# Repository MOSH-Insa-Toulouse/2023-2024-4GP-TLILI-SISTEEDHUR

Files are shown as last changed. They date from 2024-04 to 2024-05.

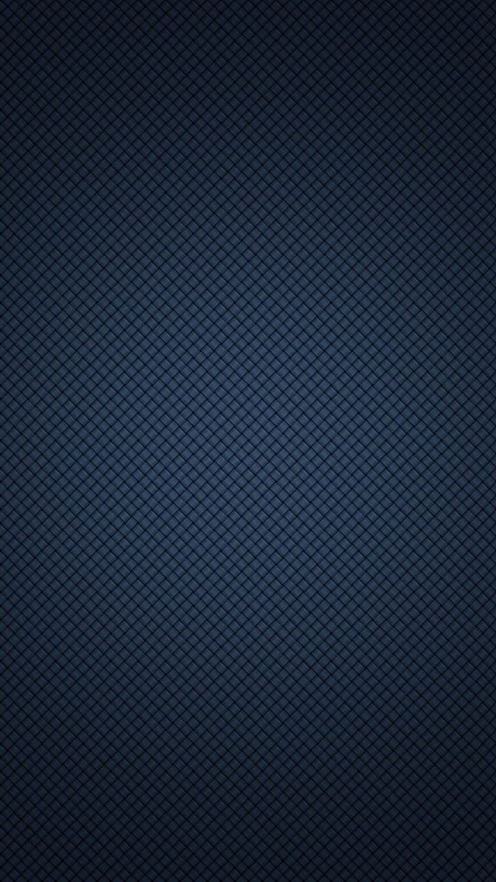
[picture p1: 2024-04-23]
Images/APKlike/Carbon Fiber.jpg

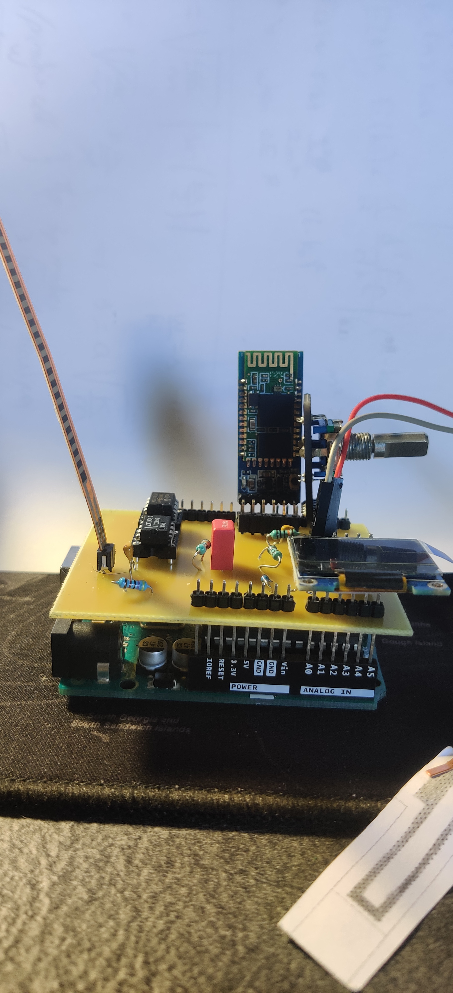
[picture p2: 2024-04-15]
Images/PCB/Shield3.jpg

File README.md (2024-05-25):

<h1 align="center"> Projet Capteur graphite </h1>
<h2 align="center"> TLILI Maxime - SISTEEDHUR Lakshitaa </h2>
<h3 align="center"> INSA Toulouse - département Génie Physique - 2024 </h3>

Shield2

## Introduction au projet

&nbsp;&nbsp;&nbsp;&nbsp;Ce projet se construit dans le cadre de l'UF "Du capteur au banc de test" de la 4ème année du parcours Génie Physique à l'Institut National des Sciences Appliquées (INSA) de Toulouse. Il permet une approche novatrice et lowtech dans la mesure de contrainte en se basant sur les propriétés du graphite. Il s’appuie sur l’étude de capteurs de contrainte en graphite (système granulaire) dont la résistance varie suivant la déformation du capteur (Pencil Drawn Strain Gauges and Chemiresistors on Paper Cheng-Wei Lin*, Zhibo Zhao*, Jaemyung Kim & Jiaxing Huang Department of Materials Science and Engineering, Northwestern University 2220 Campus Drive, Evanston, IL, 60208, USA).

&nbsp;&nbsp;&nbsp;&nbsp;Au cours de ce projet, nous avons réalisé un dispositif permettant de relever des mesures de contrainte à partir d'une feuille en papier sur laquelle était déposée du graphène. En déformant le capteur, sa résistance est modifiée.. Il est donc possible de réaliser un capteur de déformation low-tech, que nous appellerons par la suite "capteur graphite". Dans un premier temps, nous avons simulé le comportement du circuit analogique sur le logiciel LTSpice. Ce circuit a le double rôle d’amplifier (via un amplificateur transimpédance) et de filtrer le signal délivré par le capteur. Ensuite, un code Arduino permettant la mesure de résistance et le contrôle des différents éléments du circuit (écran OLED, module Bluetooth et potentiomètre digital) a été réalisé. Nous avons préalablement testé notre circuit et le code en montant les différents éléments sur une breadboard. Ensuite, nous avons designé un PCB grâce au logiciel KiCad constituant le shield qui se fixe sur une carte Arduino UNO.

## Livrables

Les livrables du projet sont :
    - [] Le PCB du Shield Arduino
    - [] Le code Arduino permettant de faire la mesure de la résistance du capteur graphite
    - [] L'application Android pour un pilotage bluetooth du système
    - [] le banc de test du capteur
    - [] Le datasheet du capteur
    
Pour notre projet, nous avons opté pour ajouter un écran OLED servant de menu, du flex sensor commercial pour avoir un comparatif avec notre capteur, ainsi que d'un encodeur rotatoire pour différentes fonctionnalités.

## Sommaire
***
- [Matériel nécéssaire](#matériel-nécéssaire)
- [1. Simulation électronique du capteur graphite sous LTSpice](#1-simulation-électronique-du-capteur-graphite-sous-ltspice)
- [2. PCB via KiCad](#2-pcb-via-kicad)
- [3. Réalisation du Shield](#3-réalisation-du-shield)
- [4. Code Arduino](#4-code-arduino)
- [5. Application Android](#5-application-android)
- [6. Banc de test](#6-banc-de-test)
- [Datasheet](#datasheet)
- [Contact](#contact)

## Matériel nécéssaire

 - 1 Carte [Arduino UNO](https://store.arduino.cc/products/arduino-uno-rev3)
 - 1 Ecran [OLED-01](https://www.gotronic.fr/art-afficheur-oled-0-96-i2c-oled01-31506.htm)  128x64
 - 1 Amplificateur Opérationnel [LTC1050](https://www.analog.com/en/products/ltc1050.html)
 - 1 Potentiomètre Digital [MCP-41050](https://www.microchip.com/en-us/product/mcp41050)
 - 1 Module Bluetooth [HC-05](https://www.gotronic.fr/art-module-bluetooth-hc05-26097.htm)
 - 1 Encodeur Rotatoire [KY-040](https://www.az-delivery.de/fr/products/drehimpulsgeber-modul)
 - 1 Capteur [FLEXSENSOR](https://store.spectrasymbol.com/products/flex-sensor)
 - 5 Résistances (X2 100kOhm, X1 47kOhm, X1 10kOhm, X1 1kOhm)
 - 4 Condensateurs (X3 100nF, X1 1uF)
 - Crayons (HB, 2B,...)
 - Modèle papier du capteur graphite

## 1. Simulation électronique du capteur graphite sous LTSpice

&nbsp;&nbsp;&nbsp;&nbsp;Sur le logiciel LTSpice, nous avons réalisé une simulation électrique du circuit par application du schéma suivant :

Circuit LTSpice

La résistance variable de notre capteur étant de l'ordre du GigaOhm, le courant généré est très faible (de l'ordre de quelques nA). Afin de délivrer une tension suffisante au niveau du convertisseur analogique-numérique d'une carte Arduino UNO, il est nécessaire d'amplifier le signal en amont de la mesure. On réalise donc un amplificateur opérationnel transimpédance. Nous avons choisi le circuit amplificateur LTC 1050 au vu de ses paramètres de tension d'offset faible. Celle-ci ne doit pas fausser les valeurs de tensions que reçoit l'Arduino. Il est aussi nécessaire de réaliser un traitement du bruit lié à l'environnement de la mesure. C'est le rôle des différents filtres qui atténuent les bruits du réseau électrique et des horloges des composants.

Cette simulation nous permet de savoir que l'Arduino UNO est capable de mesurer le signal du capteur.

## 2. PCB via KiCad

### a. Création du PCB
&nbsp;&nbsp;&nbsp;&nbsp;Cette partie concerne la conception du circuit transimpédance sur Kicad 8.0 avec l'ajout de divers composants : 
- La résistance R2 a été remplacé par le potentiomètre digital MPC-41050. Il permet d'ajuster le gain du montage en simulant une résistance variable entre 0 et 50kOhms 
- Un module bluetooth HC-05 a été ajouté pour rendre possible une communication avec une application mobile
- Un écran OLED permet de faire l'interface homme-machine en affichant les informations
- Un flexsensor a été ajouté en tant que capteur témoin
- Un encodeur rotatoire ajoute des fonctionalités pour interagir avec les autres composants. ça permet de naviguer dans les menus de l'écran OLED et de lancer la mesure

A partir d'un template d'une carte Arduino UNO, il a fallu :
- Concevoir le schématique du circuit en important et en créant les symbôles pour chaque composant
- Corréler chaque composant à une empreinte réelle en fonction de ses caractéristiques physiques (nombre de pins, distance entre deux pins,...)
- Placer les composants sur la partie schématique et réaliser le routage du circuit
- Poser un plan de masse pour faire le référencement au GND
Afin de s'assurer de la validité du PCB, nous avons été contraint à l'utilisation de deux vias.

Nous avons listé ci-dessous les symbôles et empreintes des composants, ainsi que le schématique et son PCB final

### b. Symbôles et empreintes

- amplificateur transimpédance

Amplificateur transimpédance Symbol

- Capteur graphite

Capteur Graphite Symbol
Capteur Graphite footprint

- Amplificateur LTC1050

LTC 1050 Symbol
LTC 1050 footprint

- Flexsensor

Flexsensor Symbol
Flexsensor footprint

- Module bluetooth HC-05

Bluetooth HC-05 Symbol
Bluetooth HC-05 footprint

- Potentiomètre digital MPC41050

MPC41050 Symbol
MCP41050 footprint

- Encodeur rotatoire KY-040
KY-040 Symbol
KY-040 footprint

- Ecran OLED
OLED Screen Symbol
OLED Screen footprint

### c. Schématique et PCB final
- Schéma complet

    Schematics

- PCB

    PCB2
    PCB1

- Modèle 3D

Top view
Angle view

## 3. Réalisation du Shield

&nbsp;&nbsp;&nbsp;&nbsp;Une fois le schéma PCB réalisé, nous avons sorti le circuit sur un calque à l'échelle 1:1. Il a joué le rôle de masque dans la gravure chimique sur une plaquette d'époxy recouverte d'une couche de cuivre d'une épaisseur d'environ 60um. La plaquette a été couverte d'une résine positive, puis elle a été insolé aux UVs. Nous avons plongé la plaquette dans un révélateur et dans du perchlorure de fer pour s'affranchir de la partie de la résine non isolée et du cuivre non protégé. Cette opération s'est déroulée au sein du bâtiment du département du Génie Electrique et Informatique de l'INSA Toulouse.

&nbsp;&nbsp;&nbsp;&nbsp;L'étape suivante a été le perçage mécanique des trous sur la plaquette, et la soudure des différents composants. Nous avons utilisés deux forets mécaniques : un de diamètre 1mm pour les broches de connexion avec la carte Arduino, et un de diamètre 0.8mm pour tout autre trou. Pour ce qui est de nos deux vias, nous avons soudé des fils sur la partie non visible du PCB.

Shield1

## 4. Code Arduino

&nbsp;&nbsp;&nbsp;&nbsp;Pour faire la mesure de la résistance, nous avons créé un programme Arduino. Lorsqu'on maintient appuyé le bouton de l'encodeur rotatoire, la mesure de résistance se fait à un intervalle d'environ une seconde. La valeur nous est transmise par le biais de l'écran OLED.

&nbsp;&nbsp;&nbsp;&nbsp;Nous avons fournis trois fichiers de code :

- [Capteur2024V1.0.1](https://github.com/MOSH-Insa-Toulouse/2023-2024-4GP-TLILI-SISTEEDHUR/tree/main/Arduino/Capteur2024V1.0.1) : c'est la version qui fournit trois menus sur l'écran OLED permettant de choisir entre le mode Mesureflex, le mode MesureCG, et le mode calibration. Ce programme ne permet pas de faire de mesures. Dès lors que nous demandons de lire une mesure, l'écran OLED ne s'initialise plus et le programme plante
- [Capteur2024V2](https://github.com/MOSH-Insa-Toulouse/2023-2024-4GP-TLILI-SISTEEDHUR/tree/main/Arduino/Capteur2024V2.0/Capteur2024_V2.0) : C'est la version qui marche. Elle décrit le protocole présenté au dessus.
- [Test Components](https://github.com/MOSH-Insa-Toulouse/2023-2024-4GP-TLILI-SISTEEDHUR/tree/main/Arduino/Test%20Components/Test_OLED) : c'est un programme permettant de tester l'écran OLED.

Affichage_ecran_OLED

## 5. Application Android

&nbsp;&nbsp;&nbsp;&nbsp;Nous avons réalisé une application android nommée FlexiGraphite.apk. Elle permet d'interagir par bluetooth avec le capteur graphite et de relever notamment la valeur de la résistance du capteur graphite.

Logo :
FlexiGraphite

Menu de l'application :
Menu FlexiGraphite

On retrouve 3 parties sur le menu : 
- La connexion bluetooth au dessus, avec la possibilité de voir l'état de la connexion et de se déconnecter de tout appareil.
- L'onglet "Mesure" servant à y afficher les mesures de la résistance graphite.
- L'onglet "Calibration" qui permet de piloter le lancement de la calibration du gain transimpédance.

## 6. Banc de test

&nbsp;&nbsp;&nbsp;&nbsp;Afin de tester notre capteur, nous avons réalisé un banc de test. Le support est un ensemble de demi-cercles dont le rayon varie. 

BancDeTest
Formule

Pour les crayons B et HB, on calcule la déformation en fonction du rayon du banc de test et on fait la mesure de résistance. On reporte les valeurs dans un graphe pour tracer l'évolution de la variation de résistance en fonction de la déformation.

deformation en compression

Déformation en tension

Deformation flexsensor

## Datasheet
Le datasheet de notre capteur se trouve [ici](https://github.com/MOSH-Insa-Toulouse/2023-2024-4GP-TLILI-SISTEEDHUR/blob/main/Datasheet/Datasheet%20Graphite%20Flex%20Sensor.pdf). 

## **Contact:**
- Maxime Tlili : tlili@insa-toulouse.fr
- Lakshitaa Devi Sisteedhur : sisteedh@insa-toulouse.fr

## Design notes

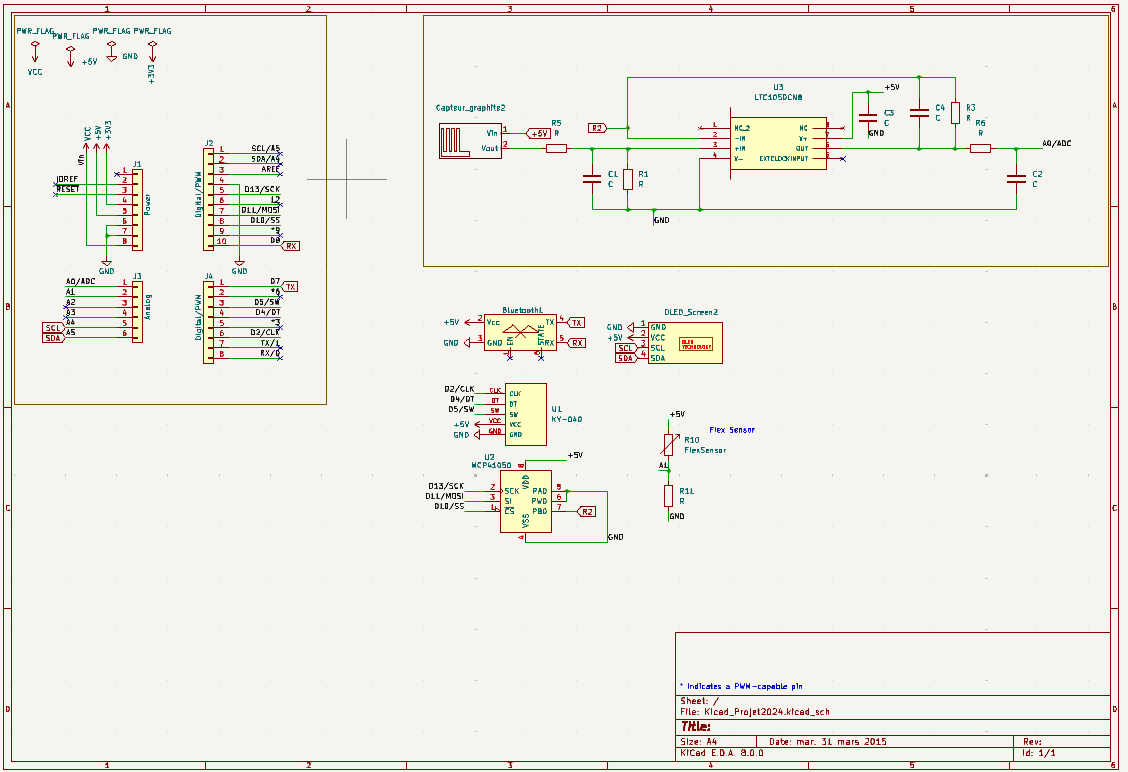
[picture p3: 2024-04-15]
Images/Kicad/Schematics.png

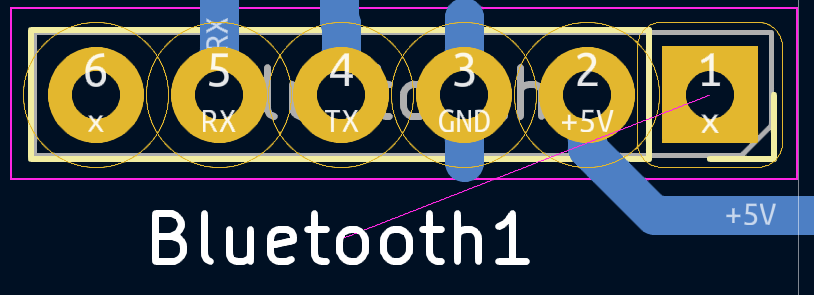
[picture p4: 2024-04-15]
Images/Kicad/Bluetooth HC-05 footprint.png

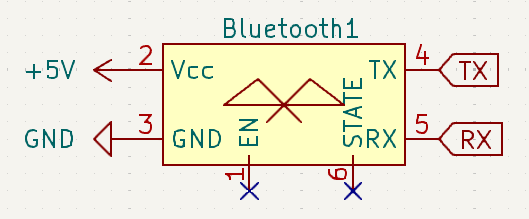
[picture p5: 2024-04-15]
Images/Kicad/Bluetooth HC-05 Symbol.png

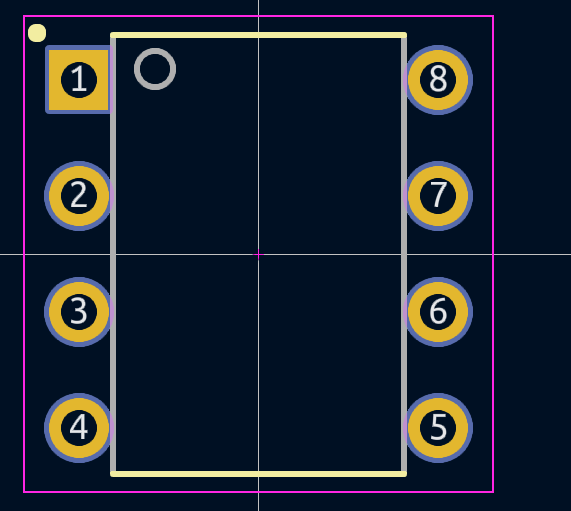
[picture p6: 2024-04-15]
Images/Kicad/MCP41050 footprint.png

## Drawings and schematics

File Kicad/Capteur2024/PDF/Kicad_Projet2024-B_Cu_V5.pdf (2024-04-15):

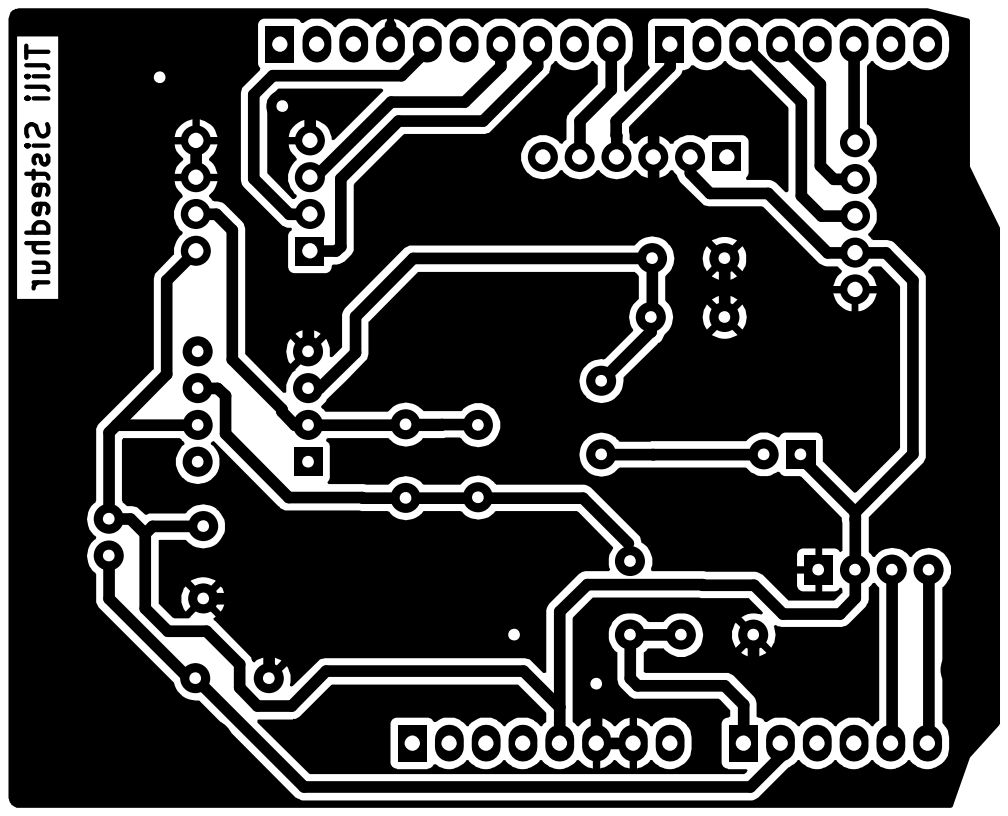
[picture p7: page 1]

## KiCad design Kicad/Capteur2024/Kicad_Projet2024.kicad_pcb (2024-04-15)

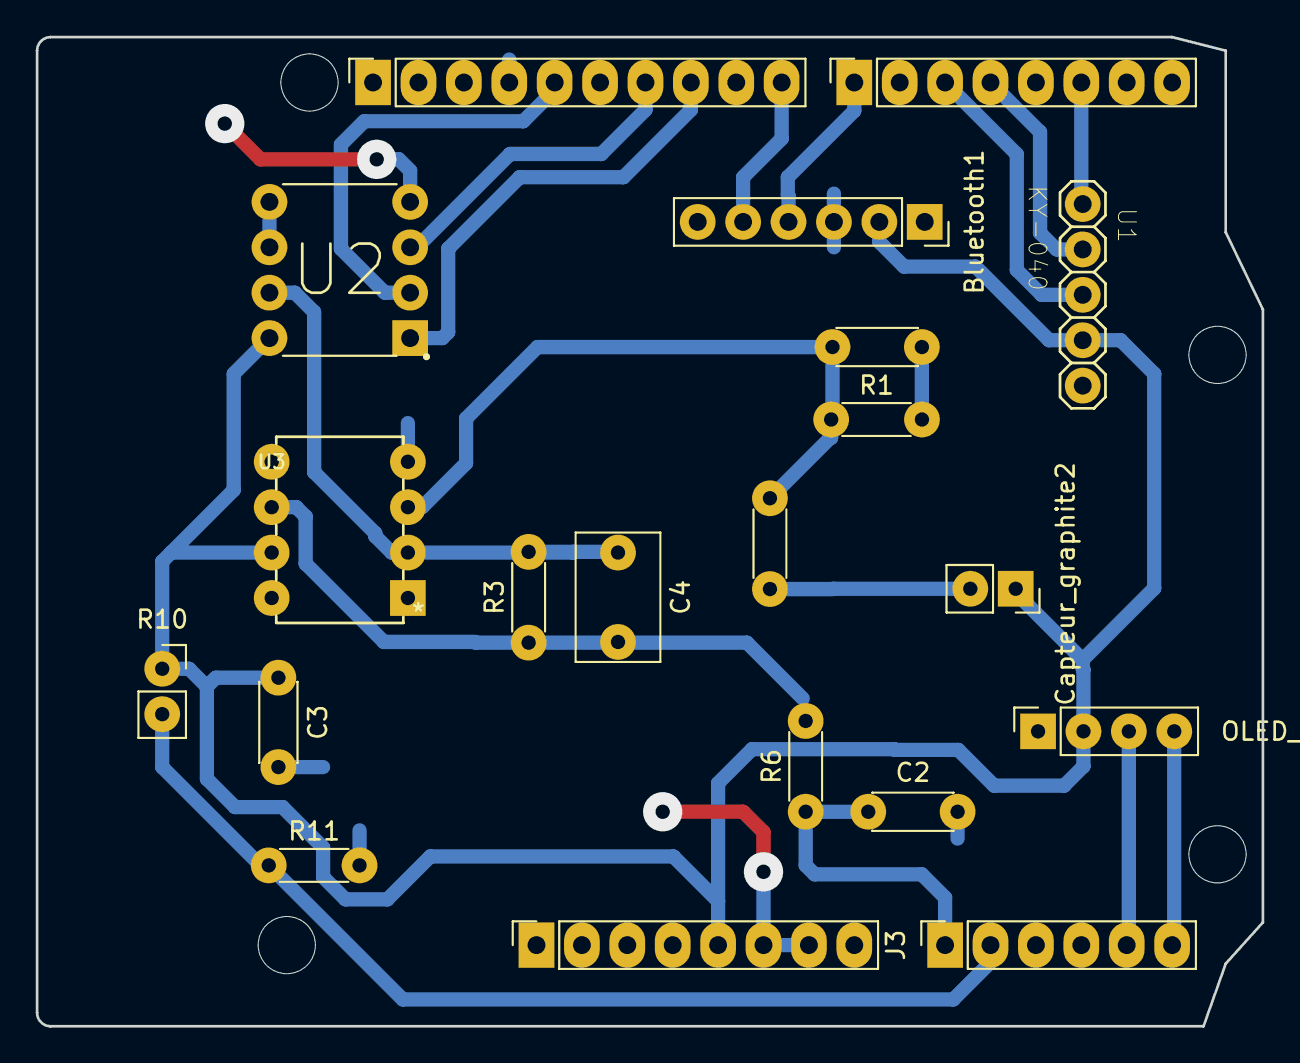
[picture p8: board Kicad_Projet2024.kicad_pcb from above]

Board: 2 copper layers, 68.6 x 55.3 mm, 24 parts (0 on the bottom side), 18 nets.

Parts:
Bluetooth1: PinSocket_1x06_P2.54mm_Vertical
C1, C2, C3: C; C_Disc_D4.3mm_W1.9mm_P5.00mm
C4: C; C_Rect_L7.0mm_W4.5mm_P5.00mm
Capteur_graphite2: PinSocket_1x02_P2.54mm_Vertical
J1: Power; PinSocket_1x08_P2.54mm_Vertical
J2: Digital/PWM; PinSocket_1x10_P2.54mm_Vertical
J3: Analog; PinSocket_1x06_P2.54mm_Vertical
J4: Digital/PWM; PinSocket_1x08_P2.54mm_Vertical
MH1, MH2, MH3, MH4: MountingHole_3.2mm
OLED_Screen2: PinSocket_1x04_P2.54mm_Vertical
R1, R3, R5, R6, R11: R; R_Axial_DIN0204_L3.6mm_D1.6mm_P5.08mm_Horizontal
R10: FlexSensor; PinSocket_1x02_P2.54mm_Vertical
U1: KY-040; KY-040-PORT
U2: MCP41050; MPC41050_IP
U3: LTC1050CN8

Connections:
+5V: Bluetooth1.2 (Vcc), C3.1, Capteur_graphite2.1 (Vin), J1.5, OLED_Screen2.2 (VCC), R10.1, U1.VCC, U2.8 (VDD), U3.7 (V+)
/A0/ADC: C2.1, J3.1, R6.1
/A1: J3.2, R10.2, R11.1
/D2/CLK: J4.6, U1.CLK
/D4/DT: J4.4, U1.DT
/D5/SW: J4.3, U1.SW
/D10/SS: J2.8, U2.1 (~CS)
/D11/MOSI: J2.7, U2.3 (SI)
/D13/SCK: J2.5, U2.2 (SCK)
GND: Bluetooth1.3 (GND), C1.2, C2.2, C3.2, J1.6, J1.7, J2.4, OLED_Screen2.1 (GND), R1.2, R11.2, U1.GND, U2.4 (VSS), U2.5 (PA0), U2.6 (PW0), U3.4 (V-)
unnamed: Capteur_graphite2.2 (Vout), R5.1
unnamed: C1.1, R1.1, R5.2, U3.3 (+IN)
unnamed: C4.2, R3.1, R6.2, U3.6 (OUT)
R2: C4.1, R3.2, U2.7 (PB0), U3.2 (-IN)
RX: Bluetooth1.5 (RX), J2.10
SCL: J3.5, OLED_Screen2.3 (SCL)
SDA: J3.6, OLED_Screen2.4 (SDA)
TX: Bluetooth1.4 (TX), J4.1

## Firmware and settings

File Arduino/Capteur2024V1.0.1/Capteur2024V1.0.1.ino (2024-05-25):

#include <SoftwareSerial.h>                 //Module Bluetooth
#include <Adafruit_SSD1306.h>               //Ecran OLED
#include <Adafruit_GFX.h>
#include <SPI.h>                            //Potentiometre MCP41xxx


    // ~~~~~~~~~~~~ Définition des pins ~~~~~~~~~~~~ //

#define ADCPin A0                           // Ampli CG
#define flexPin A1                          // FlexSensor
#define encoder0PinA  2                     // CLK Encodeur KY-040
#define encoder0PinB  4                     // DT Encodeur KY-040
#define Switch 5                            // Switch Encodeur KY-040
#define txPin 7                             // A raccorder au TX du HC-05
#define rxPin 8                             // A raccorder au RX du HC-05
#define csMCpin 10                          // Slave Select du potentiometre

/*
SRD OLED- to analog pin A4
CLK OLED- to analog pin A5
SDI MCP41- to digital pin 11 (MOSI pin)
CLK MCP41- to digital pin 13 (SCK pin)
*/

#define baudrate 9600

    // ~~~~~~~~~~~~ Paramètres de l'écran OLED ~~~~~~~~~~~~ //

#define nombreDePixelsEnLargeur 128         // Largeur de l'écran OLED en pixel
#define nombreDePixelsEnHauteur 64          // Hauteur de l'écran OLED en pixel
#define brocheResetOLED         -1          // Reset de l'OLED partagé avec l'Arduino
#define adresseI2CecranOLED     0x3C        // Adresse I2C de l'écran OLED 

int currentMode = 0;                        // Mode actuel du menu
#define NUM_MODES 3                         // Nombre total de modes disponibles
String modeNames[NUM_MODES] = {"Mesure CG", "Mesure Flex", "Calibration"};  // Noms des modes

    // ~~~~~~~~~~~~ Paramètres du potentiomètre digital ~~~~~~~~~~~~ //

const int  maxPositions    = 256;           // wiper can move from 0 to 255 = 256 positions
const long rAB             = 46250;         // 50k pot resistance between terminals A and B, 
                                            // mais pour ajuster au multimètre, je mets 46250 : à vérifier
const byte rWiper          = 125;           // 125 ohms pot wiper resistance
const byte pot0            = 0x11;          // pot0 addr // B 0001 0001
const byte pot0Shutdown    = 0x21;          // pot0 shutdown // B 0010 0001

    // ~~~~~~~~~~~~ Paramètres du flexsensor ~~~~~~~~~~~~ //

const float VCC = 5;
const float flexR_DIV = 47000.0;
const float flexflatResistance = 30000.0;
const float flexbendResistance = 1000.0;


volatile unsigned int encoder0Pos = 0; //Initialisation de la position de l'encodeur

SoftwareSerial Bluetooth_Serial(rxPin ,txPin);
Adafruit_SSD1306 ecranOLED(nombreDePixelsEnLargeur, nombreDePixelsEnHauteur, &Wire, brocheResetOLED);


    // ~~~~~~~~~~~~ Paramètres de mesure ~~~~~~~~~~~~//

float Calibre = pow(10,-6);               // Afin d'avoir des Mohms
unsigned long antidelay = 0;              // Eviter le delay 
const long interval = 500;                // Cadencement de l'acquisition


    // ~~~~~~~~~~~~ Fonctions ~~~~~~~~~~~~ //

long setPotWiper(int addr, int pos) {   // Fonction permettant de fixer la position du potentiomètre 
                                        // Et donc de fixer la valeur de R2. Affiche la postion et la valeur de R2
  pos = constrain(pos, 0, 255);         // On limite les pads de 0 à 255
  digitalWrite(csMCpin, LOW);             // En position LOW, on active le chip select qui nous permet d'écrire    
  SPI.transfer(addr);                   // Configurer la position du potentiomètre "addr" sur "pos"
  SPI.transfer(pos);
  digitalWrite(csMCpin, HIGH);            // En position HIGH, on se déconnecte du CS

  long resistanceWB = ((rAB * pos) / maxPositions ) + rWiper; //Formule donnée dans la datasheet liant R2 et les paramètres
  
  return resistanceWB;
}

void calibration(){             //Fonction permettant de réaliser une calibration de la résistance R2 de l'ampli
  
  float R2_value;
  float Tension_sortie;         // variable qui stocke la tension en sortie de l'ampli
  int i = 0;
  do
  {
      R2_value = setPotWiper(pot0, i);
      Tension_sortie = ADCPin;
      delay(200); // A vérifier si le delai n'est pas trop court
      i++;
  } while ((/*Ampli A0 */ Tension_sortie <2.5 ) || (i<256)); //On set le potentio à sa valeur min et on récupère la valeur en sortie
                                              //de l'ampli. On répète l'opération pour se rapprocher des 2.5V (au milieu de la gamme de l'arduino) 

}

void bluetooth(){                 // A vérifier si important et à mettre dans le loop//
    int i = 0; 
	char someChar[32] ={0};
	//when characters arrive over the serial port...

	while (Serial.available()) {
	   do{
		someChar[i++] = Serial.read();
		delay(3);		
	   }while (Serial.available() > 0);
	   
	   Bluetooth_Serial.println(someChar); 
	   Serial.println(someChar); 
	}
	while (Bluetooth_Serial.available()) {
		Serial.print((char)Bluetooth_Serial.read());
	}
}

void doEncoder() {              //Paramètrage de l'encodeur rotatoire
  if (digitalRead(encoder0PinB)==HIGH) {  //On tourne l'encodeur dans le sens anti-trigonométrique. Incrémentation de la position//
    encoder0Pos++;
  } else {                                //On tourne l'encodeur dans le sens trigonométrique. Décrémentation de la position//
    encoder0Pos--;
  }
}

void mesureFlex() {             //Fait la mesure de la résistance et de l'angle du capteur
  int ADCflex = analogRead(flexPin);                          //Read du pin A1 lié au flexsensor
  float Vflex = ADCflex * VCC / 1023.0;                       //Calcul de la tension aux bornes du capteur 
  float Rflex = flexR_DIV * (VCC / Vflex - 1.0);                  //Calcul de la résistance du capteur
  Serial.println("Resistance: " + String(Rflex) + " ohms");   //Affichage de la résistance

  float angle = map(Rflex, flexflatResistance, flexbendResistance, 0, 90.0);  //estimation de l'angle de courbure du capteur
  Serial.println("Bend: " + String(angle-21.0)  + " degrees");              //affichage de l'angle de courbure du capteur
  Serial.println();
}

void mesureCapteur() {          //Fait la mesure de la tension du capteur graphite
  float Vgraphite = analogRead(ADCPin) * 5.0/1023.0; // Conversion des incréments digits de 0 à 1023 à une tension entre 0 et 5 volts
  Serial.println("Tension du capteur graphite: " + String(Vgraphite) + "V");

}









void setup() {

  Serial.begin(baudrate); // définition du Baudrate


    // ~~~~~~~~~~~~ Bluetooth HC-05 ~~~~~~~~~~~~ //

  pinMode(rxPin,INPUT);
  pinMode(txPin,OUTPUT);
  Bluetooth_Serial.begin(baudrate);
  

    // ~~~~~~~~~~~~ Potentiomètre digital MCP ~~~~~~~~~~~~ //

  digitalWrite(csMCpin, HIGH);        // chip select default to de-selected
  pinMode(csMCpin, OUTPUT);           // configure chip select as output
  SPI.begin();


    // ~~~~~~~~~~~~ Ecran OLED ~~~~~~~~~~~~ // 

  if(!ecranOLED.begin(SSD1306_SWITCHCAPVCC, adresseI2CecranOLED)){
    Serial.println("Echec de l'initialisation de l'écran OLED");
    while(1);                               // Arrêt du programme (boucle infinie) si échec d'initialisation
  }
  ecranOLED.clearDisplay();           //Effacer le contenu de l'écran OLED
  displayMainMenu();                  //Afficher le Menu principal de l'écran OLED

    // ~~~~~~~~~~~~ FlexSensor ~~~~~~~~~~~~ //

  pinMode(flexPin,INPUT);

    // ~~~~~~~~~~~~ Encodeur rotatoire ~~~~~~~~~~~~ //

  pinMode(encoder0PinA, INPUT);
  digitalWrite(encoder0PinA, HIGH);         //turn on pullup resistor
  pinMode(encoder0PinB, INPUT);
  digitalWrite(encoder0PinB, HIGH);
  attachInterrupt(0, doEncoder, RISING);    //encoder pin on interupt 0 for pin 2
  pinMode(Switch, INPUT_PULLUP);



}



void loop() {
  
  //bluetooth();                        // Assure la connexion bluetooth
  ChoixDuMenu();
 
}


  // Gestion des boutons

void ChoixDuMenu(){

  if (digitalRead(encoder0PinB) == LOW) {
    currentMode = (currentMode + 1) % NUM_MODES; // Passage au mode suivant
    displayMainMenu();
    delay(200); // Délai pour éviter les rebonds
  }
  
  if (digitalRead(Switch) == LOW) {
    // Action à effectuer lors de la sélection (par exemple, passer au sous-menu correspondant)
    // Ici, nous allons simplement afficher le nom du mode sélectionné
    displaySubMenu(currentMode);
    delay(5000); // Délai pour laisser le temps de lire l'affichage
    displayMainMenu(); // Retour au menu principal après la sélection
  }
}

// Fonction pour afficher le menu principal avec les différents modes
void displayMainMenu() {
  ecranOLED.clearDisplay();
  ecranOLED.setTextSize(1);
  ecranOLED.setCursor(0,0);
  
  // Affichage des noms des modes
  for (int i = 0; i < NUM_MODES; i++) {
    if (i == currentMode) {
      ecranOLED.setTextColor(SSD1306_BLACK, SSD1306_WHITE);
      ecranOLED.print(">");
    } else {
      ecranOLED.setTextColor(SSD1306_WHITE, SSD1306_BLACK);
      ecranOLED.print(" ");
    }
    ecranOLED.println(modeNames[i]);
  }
  
  ecranOLED.display();
}

// Fonction pour afficher le sous-menu correspondant au mode sélectionné
void displaySubMenu(int mode) {
  ecranOLED.clearDisplay();
  ecranOLED.setTextSize(1);
  ecranOLED.setTextColor(SSD1306_WHITE);
  ecranOLED.setCursor(0,0);
  
  // Affichage du sous-menu en fonction du mode sélectionné
  switch (mode) {
    case 0:
      ecranOLED.println("Mode 'Mesure CG'");
      Serial.println("mode mesure CG");
      break;
    case 1:
      ecranOLED.println("Mode 'Mesure Flex'");
      delay(200);
      int ADCflex = analogRead(flexPin);                          //Read du pin A1 lié au flexsensor
      float Vflex = ADCflex * VCC / 1023.0;                       //Calcul de la tension aux bornes du capteur 
      float Rflex = flexR_DIV * (VCC / Vflex - 1.0);                  //Calcul de la résistance du capteur
      Serial.println("Resistance: " + String(Rflex) + " ohms");   //Affichage de la résistance
      break;
    case 2:
      ecranOLED.println("Mode 'Calibration'");
      ecranOLED.println("...");
      ecranOLED.println("Calibration");
      ecranOLED.println("en cours..."); 
      break;
    default:
      ecranOLED.println("Invalid Mode");
  }
  
  ecranOLED.display();
}

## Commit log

2024-03-13 Add Kicad and Arduino 13/03/24
    [Kicad_Projet2024.kicad_pcb, Kicad_Projet2024.kicad_sch]
2024-04-12 Update README.md
    ajout de photos
2024-04-15 Mise à Jour du GitHub
    Ajout des images, de l'état du code arduino, de la mise à jour du Kicad
    [Kicad_Projet2024.kicad_pcb, Kicad_Projet2024.kicad_sch]
2024-04-23 update GitHub 23-04-2024
    [Kicad_Projet2024.kicad_pcb, Kicad_Projet2024.kicad_sch]
2024-05-25 Update README.md
    ajout des images du banc de test
